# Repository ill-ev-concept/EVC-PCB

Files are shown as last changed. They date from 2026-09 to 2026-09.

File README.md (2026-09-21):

# EVC-PCB

*By: Himesh Nasaka*

Welcome to EV Concept's PCB Repo!

This is where all of our projects are stored. 

* Boards: Contains design files of all current boards being worked on
* Libs: Contains a wide selection of schematics, footprints, and models of components that are being used

# Getting Started

Start by having Git and KiCAD 10 downloaded. If you are using a older version of KiCAD, we recommend updating to the newest version. We also recommend installing Github Desktop in order to make the usage a bit cleaner.

Clone this repo. This can be either done through terminal or Github Desktop. Click the green dropdown labeled "<> Code" and select your preference of how to clone the repo. If using terminal, run the command below

```git clone [INSERT]```

If using Desktop, you can click the dropdown menu next to current repository, then "add", and finally "clone" where we can input the repo's url. 

# Setting Paths

After cloning, open KiCAD and find the "Preferences" dropdown and select "Configure Paths".
We are going to be adding three new paths. Create three new variables, ```EVC_SYMBOL_DIR```, ```EVC_FOOTPRINT_DIR```, and ```EVC_3DMODEL_DIR```. Link these to the location of the ```symbols```, ```footprints```, and ```3d_models``` folders contained with ```libs``` folder.

<img src="./images/Configure_Paths.png" width="700" alt="Example of Correct Paths">

When designing, we will need KiCAD to know to look at a given library. We can do this by going to "Preferences" and finding either "Manage Symbol Libraries" or "Manage Footprint Libraries". Opening either brings up a window where we can select "Project Specific Libraries" where we can add paths. Click the folder icon and add the wanted library. If you set the path up correctly, the library path will contain  ```${EVC_SYMBOL_DIR}```, ```${EVC_FOOTPRINT_DIR}```, or ```${EVC_3DMODEL_DIR}```. 

<img src="./images/Correct_Lib_Path.png" width="700" alt="Example of Library Paths">

# Contributing 

In order to begin designing, create a branch for your given board. This can be done through either the "current branch" dropdown in Desktop or using the command ```git checkout -b [branch name]```. You can swap branches using the same dropdown or either ```git checkout [branch name]```. 

<img src="./images/Branch.png" width="300" alt="Desktop Branch Dropdown">

This will be the branch where you will be doing your design work. Create a new KiCAD project and save the location into the boards folder of this repo. Everything onward will be traditional git. Use ```git add``` or check off the needed boxes on Desktop to add files for commit. ```git commit -m "[MESSAGE HERE]"``` will commit your changes. Make sure to write a meaningful commit message in order for good documentation. An example is shown below.

```git commit -m "Finished designing LDO and CANBus connectors, need to add MCU pinout and decoupling caps"```

<img src="./images/Commit_Msg.png" width="300" alt="Ex. of Good Commit Msg">

Input both your contributions and the next required steps in order to give reminders to both yourself and your teammates. 

Once a board is finished or you want it reviewed, it must be submitted via a pull request. This can be done using ```git push -u origin [branch name]``` or by clicking the branch dropdown in Desktop and selecting the "create pull request" option.

<img src="./images/Create_PR.png" width="300" alt="Create PR">

This will open up a Github tab on your browser where you can edit your pull request. Give it a good title and description so the design choices are clear and understandable. A title will also help the leads parse what you guys want done. 

<img src="./images/Comp_And_PR.png" width="500" alt="PR From Git Command">

You'll see the image above if you use a command line prompt and go to the repo.

<img src="./images/PR_In_Git.png" width="400" alt="Creating a Pull Request">

After the PR is submitted, we will decide on whether the board can be pushed to main or not. If it is not pushed, we will submit comments on what needs to be reviewed and edited. You can view open PRs and their comments in Github.

Apart from designing in KiCAD, it is important to be updating the libs folder when any new schematic, footprint, or model is added. First make sure the IC you want to add isn't currently within our library. Add the path to the specific library which is detailed more above. If the IC is not located in it's library, open Symbol/Footprint editor and select the library you want to add to. I recommended clicking the "View" dropdown, selecting the "Panels" option and adding the "Library Tree" option in order to easily see the connected libraries. 

<img src="./images/Library_Tree.png" width="300" alt="Library Tree">

From this, import the downloaded model and save the file. From there, push the updated library files and create a pull request. The leads will then check your work and merge it into main so everyone can use the IC.

When making pull requests for ICs, make sure to push them individually rather than with changes to other files. This will make it more clear for reviewers to understand that library files are being edited in addition to making sure that the change will be pushed to main. If you push with changes to your board and the pull request is not granted, people will not have access to the IC you have imported. 

Because the libs folder will be constantly updated, its also important to keep your branch up to date with new changes. We can layer on changes from main into our branch using a few different methods but the main one we will be using is merge. Run the command ```git fetch origin``` and then ```git merge origin``` in order to update changes. In Desktop, you can select "Update from main" from the "Branch" dropdown. 

<img src="./images/Update_From_Main.png" width="300" alt="Update from Main">

This should not change any local files that is stored and will update the libs folder to have the newest selection of ICs. I recommend doing this every time you work on your boards. It will also make sure a merge conflict won't be created, in which the same file from two different pull requests is edited, causing a lot of hassle for the writers of this repo. 

A general outline of what the workflow may look like is shown below:

```git checkout [branch name]``` -> Run this to swap to the branch you want to work on

```git fetch origin``` -> Run this to pull updates from main. Important for having updated libs

```git merge origin/main``` -> Merges the changes from the above command

```git add [file name]``` -> Add files for commit. When updating library files, make sure to add them in individual PRs

```git commit -m "[message here]"``` -> Commits your changes to be pushed into your branch

```git push -u origin [branch name]``` -> Run this command the first time you make the branch. It will link your branch to Github. 

```git push``` -> Pushes your changes. After, you can go to Github and create a pull request for the changes to be pushed into main. **Don't create a PR for every change you do.** Only create pull requests **IF** you are editing the libs folder **OR** you are submitting for board revision **OR** it is the final revision of the board.

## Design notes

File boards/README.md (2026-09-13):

# Boards!

This is the location where you will be pushing your KiCAD files to. 
Each file should be it's own project. You should only be pushing 5 different files
- kicad_pro
- kicad_sch
- kicad_pcb
- fp-lib-table
- sym-lib-table

*Nothing else should be pushed*

I'll be adding more details later on

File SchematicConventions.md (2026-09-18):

# **Schematic Conventions**

*By: Ethan Rybka*

Please make sure to follow these as close as possible, this will make schematic review much easier for leadership, and help project progress move forwards.

<br/>

# **Introduction**
When doing schematic layout, **consistency** is key to having a readable schematic. This means that you stick to a formatting convention for the whole schematic.

# **Labels**

When using labels use **regular** or **hierarchical** labels. Only use global labels when neccesary. 

### **Naming labels**

When naming labels, do **not** use spaces, use "_" or no space instead. Generally it is best to use all capital letters when naming.

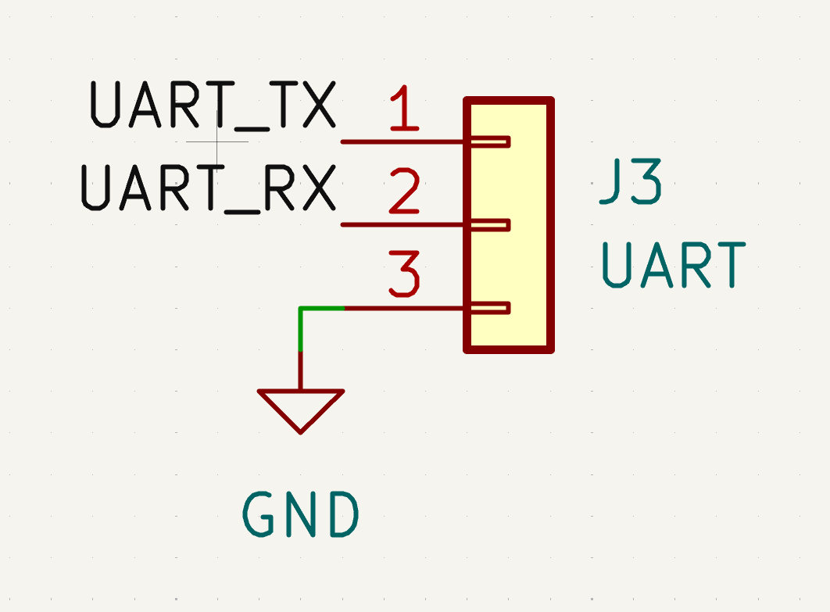
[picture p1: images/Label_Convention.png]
Label Conventions


### **Power Labels**

For power labels, GND must always face downwards, and power always upwards. Make sure you are using the built in symbols for these.

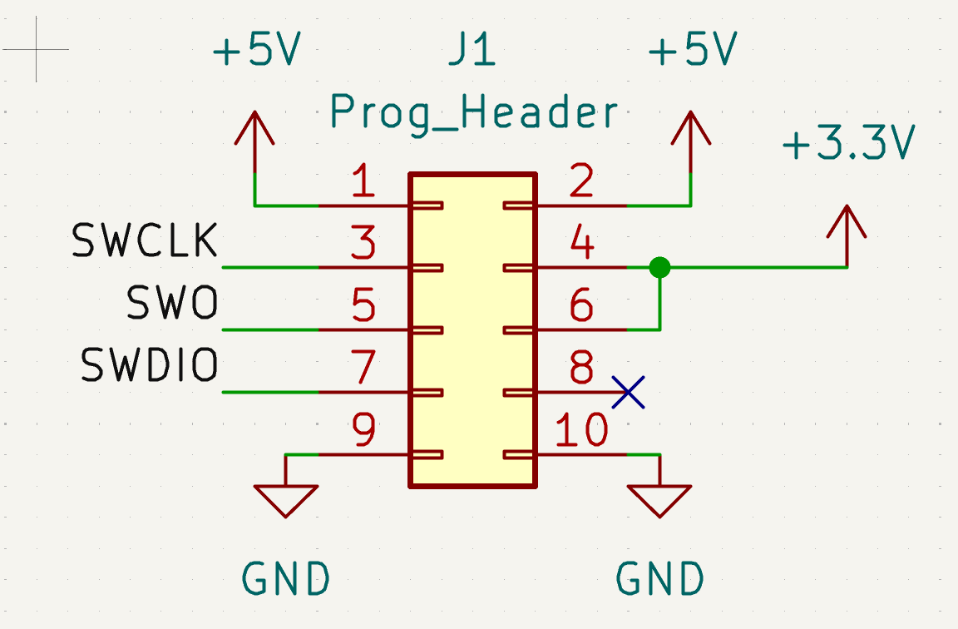
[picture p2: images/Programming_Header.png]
Power Label Conventions


# **Structure**

### **Partitions**

Whenever you can, try to group together sets of components together that have similar functionality. For example a buck converter circuit can be inside of one box.
Make sure to label each boxes function. Make sure the box has:

- 8 mil (0.25mm) line width
- Dashed lines
- Use at least 1.5mm (55 mil) text size

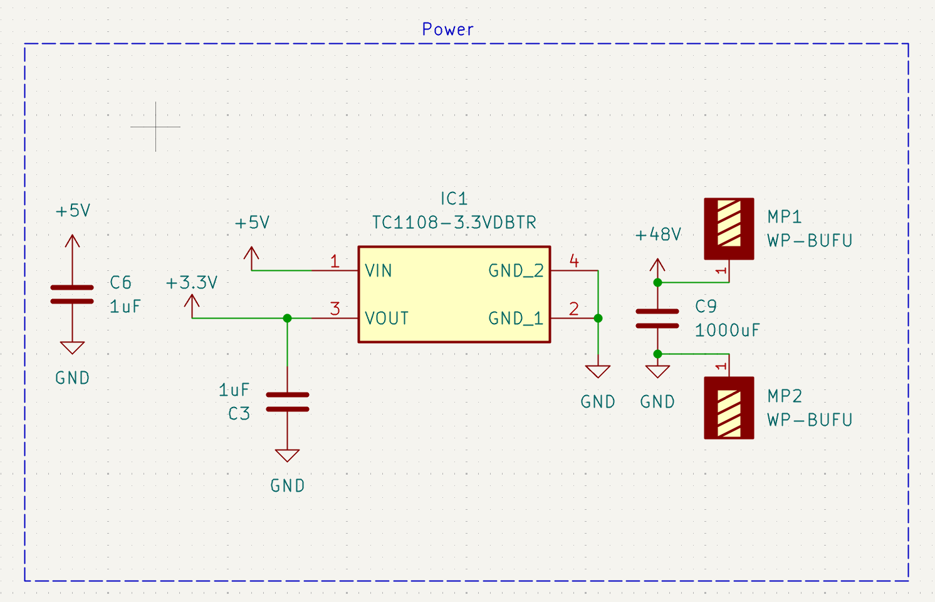
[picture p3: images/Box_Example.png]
Box/Partition Conventions


## **Sizes**

### **Page Size**

Page size can be any size, although larger sizes will be harder to print, using hierarchical sheets can help to 

### **Text**

Make sure any text follows the above 1.5 mm min text size for readability.

### **Grid** 

Keep the grid size the default size (1.27mm/50mil) if more accurate placement is needed, use half of the size (0.635mm/25mil).

### **Reference Designators & Component Values**

Make sure that components do not have overlapping designators, or component values, this helps with not only readability for you but also for whoever is reviewing your board.

## **EVC Specific Connections**

We have some specific standard layouts for connectors such as the programming headers and CANbus connections, as shown below

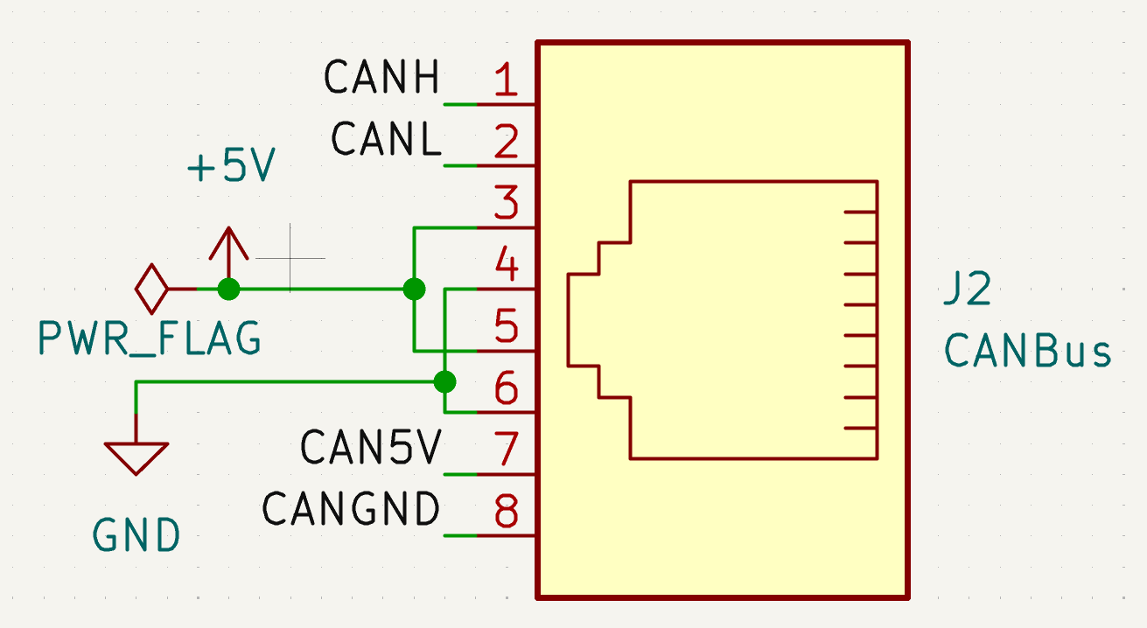
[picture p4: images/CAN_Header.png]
CAN Header
Programming Header  

# **Final Notes**

Just another reminder to be **CONSISTENT** across the entire board. This will make your life easier later on when something breaks and you have to figure why. Something will most likely go wrong the first time, nobody is perfect.

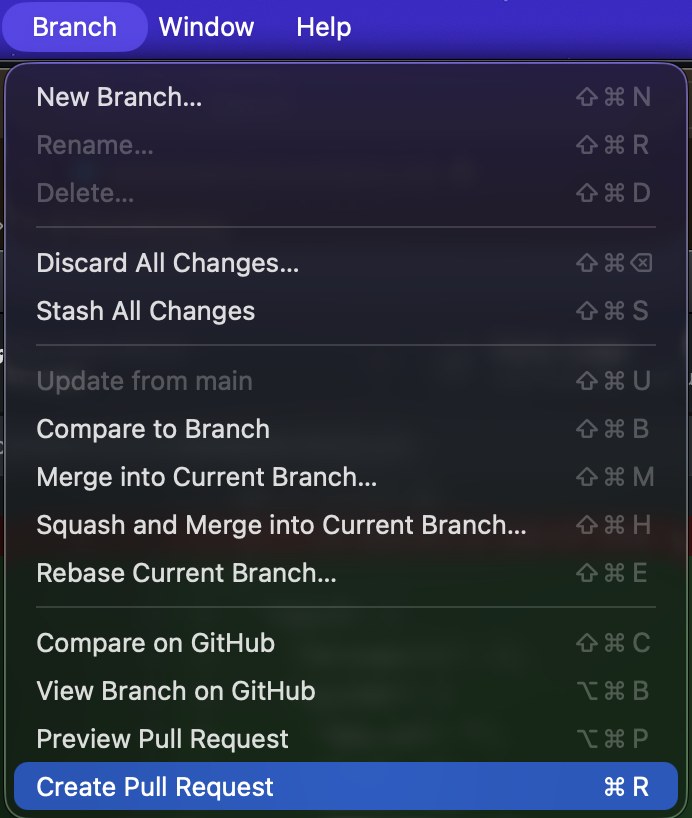
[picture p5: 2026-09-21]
images/Create_PR.png

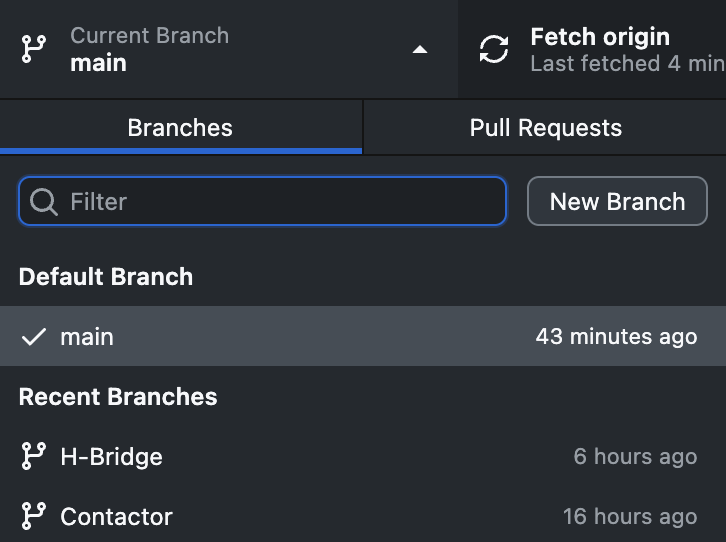
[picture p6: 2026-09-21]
images/Branch.png

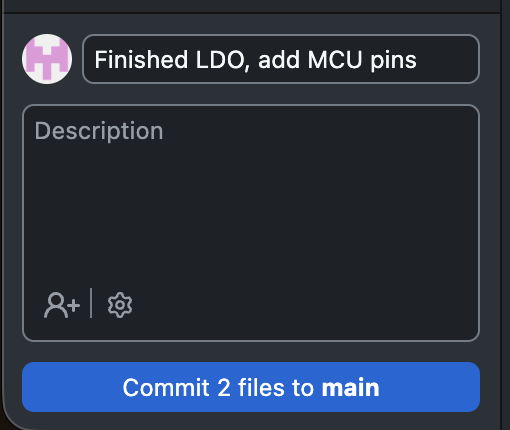
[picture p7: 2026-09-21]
images/Commit_Msg.png

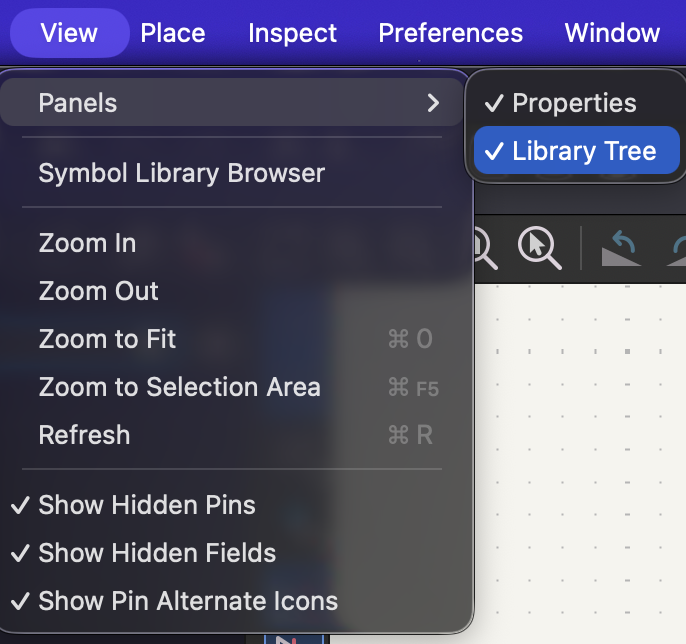
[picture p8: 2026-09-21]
images/Library_Tree.png

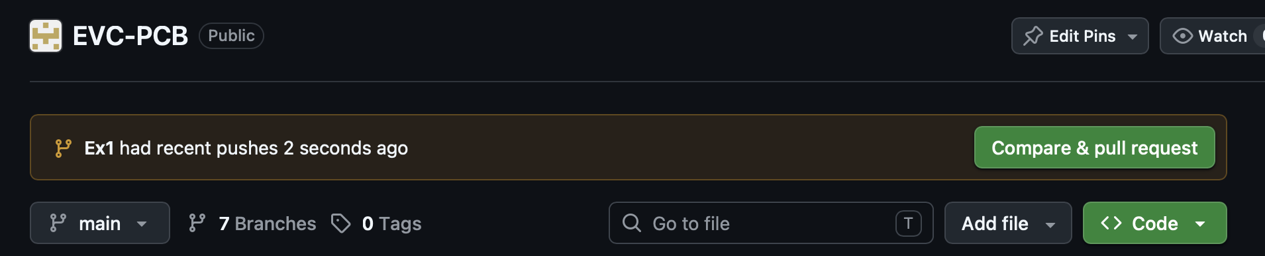
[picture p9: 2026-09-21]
images/Comp_And_PR.png

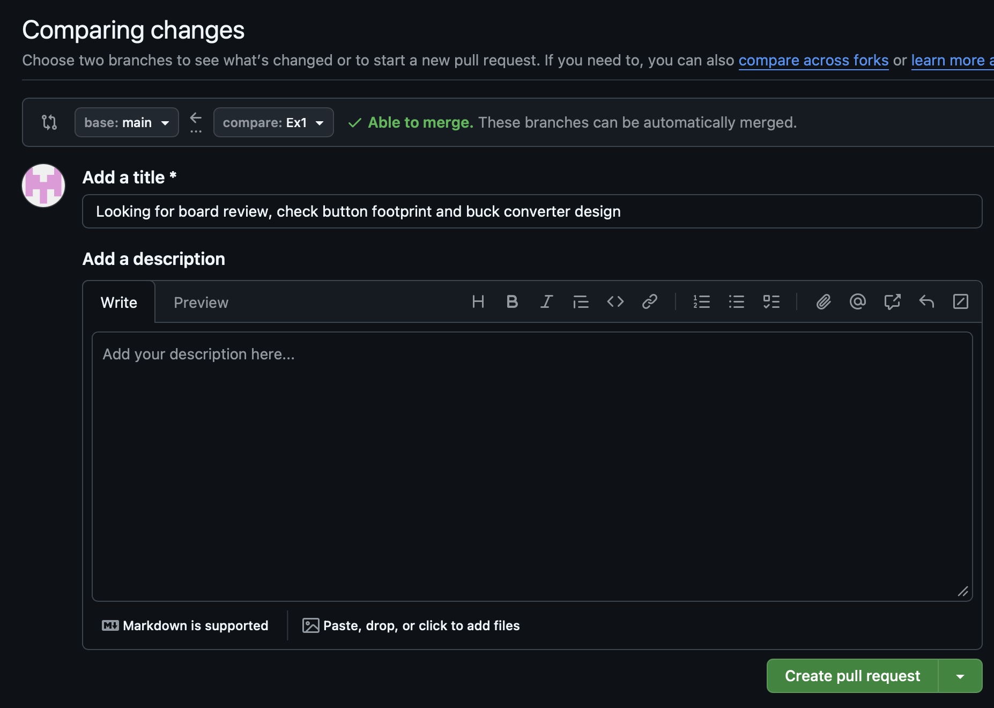
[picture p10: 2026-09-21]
images/PR_In_Git.png

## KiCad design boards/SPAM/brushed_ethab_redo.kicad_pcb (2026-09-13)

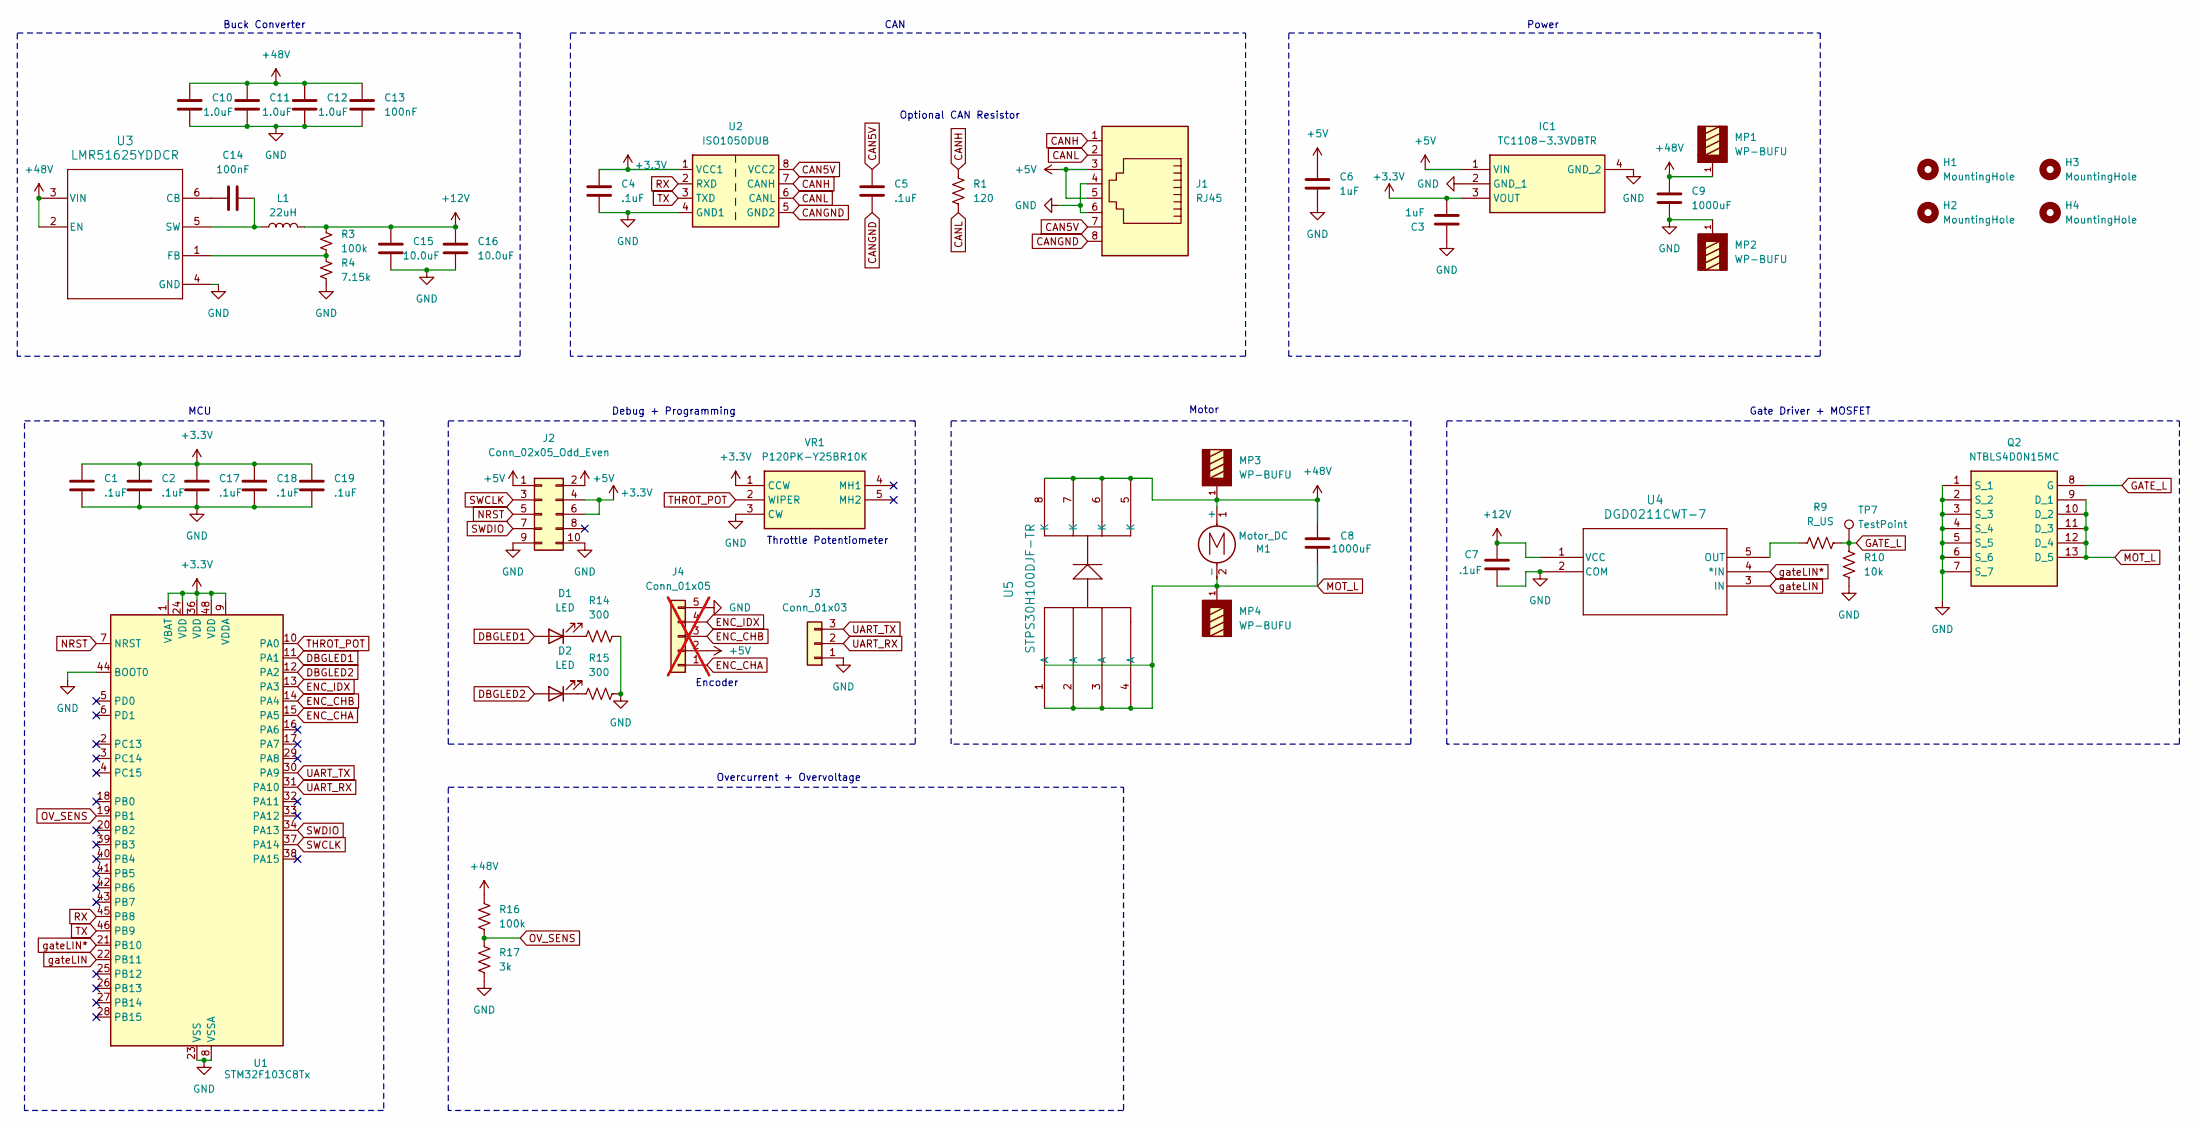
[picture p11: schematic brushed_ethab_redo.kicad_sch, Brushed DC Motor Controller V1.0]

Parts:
C1, C2, C4, C5, C7, C17, C18, C19: .1uF; C_0805_2012Metric_Pad1.18x1.45mm_HandSolder
C3, C6: 1uF; C_0805_2012Metric_Pad1.18x1.45mm_HandSolder
C8, C9: 1000uF; CP_Radial_D18.0mm_P7.50mm
C10, C11, C12: 1.0uF; C_1206_3216Metric
C13: 100nF; C_0603_1608Metric_Pad1.08x0.95mm_HandSolder
C14: 100nF; C_0402_1005Metric_Pad0.74x0.62mm_HandSolder
C15, C16: 10.0uF; C_1210_3225Metric
D1, D2: LED; LED_0805_2012Metric_Pad1.15x1.40mm_HandSolder
H1, H2, H3, H4: MountingHole; MountingHole_4.3mm_M4
IC1: TC1108-3.3VDBTR; SOT230P700X180-4N; Manufacturer_Part_Number TC1108-3.3VDBTR; Mouser Part Number 579-TC1108-3.3VDBTR
J1: RJ45; RJ45_Amphenol_54602-x08_Horizontal
J2: Conn_02x05_Odd_Even; PinSocket_2x05_P2.54mm_Vertical
J3: Conn_01x03; PinSocket_1x03_P2.54mm_Vertical
J4: Conn_01x05; PinSocket_1x05_P2.54mm_Vertical; not fitted
L1: 22uH; L_Bourns_SRR1208_12.7x12.7mm
M1: Motor_DC
MP1, MP2, MP3, MP4: WP-BUFU; WP-BUFU_7461097; DigiKey_Part_Number 732-3217-ND
Q2: NTBLS4D0N15MC; Manufacturer_Part_Number NTBLS4D0N15MC; Mouser Part Number 863-NTBLS4D0N15MC
R1: 120; R_0805_2012Metric_Pad1.20x1.40mm_HandSolder
R3: 100k; R_0402_1005Metric_Pad0.72x0.64mm_HandSolder
R4: 7.15k; R_0603_1608Metric_Pad0.98x0.95mm_HandSolder
R9: R_US; R_0805_2012Metric_Pad1.20x1.40mm_HandSolder
R10: 10k; R_0805_2012Metric_Pad1.20x1.40mm_HandSolder
R14, R15: 300; R_0805_2012Metric_Pad1.20x1.40mm_HandSolder
R16: 100k; R_0805_2012Metric_Pad1.20x1.40mm_HandSolder
R17: 3k; R_0805_2012Metric_Pad1.20x1.40mm_HandSolder
TP7: TestPoint; TestPoint_Pad_D1.0mm
U1: STM32F103C8Tx; LQFP-48_7x7mm_P0.5mm
U2: ISO1050DUB; SOP-8_6.62x9.15mm_P2.54mm
U3: LMR51625YDDCR; DDC0006A-MFG
U4: DGD0211CWT-7; TSOT25-TH_DIO
U5: STPS30H100DJF-TR; MOSFET_100DJF-TR_STM
VR1: P120PK-Y25BR10K; P120PKY25BR10K; Manufacturer_Part_Number P120PK-Y25BR10K; Mouser Part Number 858-P120PKY25BR10K

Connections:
+3.3V: C1.1, C2.1, C3.2, C4.1, C17.1, C18.1, C19.1, IC1.3 (VOUT), J2.4, J2.6, U1.1 (VBAT), U1.9 (VDDA), U1.24 (VDD), U1.36 (VDD), U1.48 (VDD), U2.1 (VCC1), VR1.1 (CCW)
+5V: C6.1, IC1.1 (VIN), J1.3, J1.5, J2.1, J2.2, J4.2
+12V: C7.1, C15.1, C16.1, L1.2, R3.1, U4.1 (VCC)
+48V: C8.1, C9.1, C10.1, C11.1, C12.1, C13.1, M1.1 (+), MP1.1, MP1.2, MP1.3, MP1.4, MP1.5, MP1.6, MP1.7, MP1.8, MP1.9, MP1.10, MP1.11, MP1.12, MP1.13, MP1.14, MP1.15, MP1.16, MP3.1, MP3.2, MP3.3, MP3.4, MP3.5, MP3.6, MP3.7, MP3.8, MP3.9, MP3.10, MP3.11, MP3.12, MP3.13, MP3.14, MP3.15, MP3.16, R16.2, U3.2 (EN), U3.3 (VIN), U5.5 (K), U5.6 (K), U5.7 (K), U5.8 (K)
CAN5V: C5.1, J1.7, U2.8 (VCC2)
CANGND: C5.2, J1.8, U2.5 (GND2)
CANH: J1.1, R1.1, U2.7 (CANH)
CANL: J1.2, R1.2, U2.6 (CANL)
DBGLED1: D1.2 (A), U1.11 (PA1)
DBGLED2: D2.2 (A), U1.12 (PA2)
ENC_CHA: J4.1, U1.15 (PA5)
ENC_CHB: J4.3, U1.14 (PA4)
ENC_IDX: J4.4, U1.13 (PA3)
GATE_L: Q2.8 (G), R9.2, R10.2, TP7.1 (1_1)
GND: C1.2, C2.2, C3.1, C4.2, C6.2, C7.2, C9.2, C10.2, C11.2, C12.2, C13.2, C15.2, C16.2, C17.2, C18.2, C19.2, IC1.2 (GND_1), IC1.4 (GND_2), J1.4, J1.6, J2.9, J2.10, J3.1, J4.5, MP2.1, MP2.2, MP2.3, MP2.4, MP2.5, MP2.6, MP2.7, MP2.8, MP2.9, MP2.10, MP2.11, MP2.12, MP2.13, MP2.14, MP2.15, MP2.16, Q2.1 (S_1), Q2.2 (S_2), Q2.3 (S_3), Q2.4 (S_4), Q2.5 (S_5), Q2.6 (S_6), Q2.7 (S_7), R4.2, R10.1, R14.2, R15.2, R17.1, U1.8 (VSSA), U1.23 (VSS), U1.35 (VSS), U1.44 (BOOT0), U1.47 (VSS), U2.4 (GND1), U3.4 (GND), U4.2 (COM), VR1.3 (CW)
MOT_L: C8.2, M1.2 (-), MP4.1, MP4.2, MP4.3, MP4.4, MP4.5, MP4.6, MP4.7, MP4.8, MP4.9, MP4.10, MP4.11, MP4.12, MP4.13, MP4.14, MP4.15, MP4.16, Q2.9 (D_1), Q2.10 (D_2), Q2.11 (D_3), Q2.12 (D_4), Q2.13 (D_5), U5.1 (A), U5.2 (A), U5.3 (A), U5.4 (A)
NRST: J2.5, U1.7 (NRST)
unnamed: D1.1 (K), R14.1
unnamed: D2.1 (K), R15.1
unnamed: C14.1, U3.6 (CB)
unnamed: R3.2, R4.1, U3.1 (FB)
unnamed: C14.2, L1.1, U3.5 (SW)
unnamed: R9.1, U4.5 (OUT)
OV_SENS: R16.1, R17.2, U1.19 (PB1)
RX: U1.45 (PB8), U2.2 (RXD)
SWCLK: J2.3, U1.37 (PA14)
SWDIO: J2.7, U1.34 (PA13)
THROT_POT: U1.10 (PA0), VR1.2 (WIPER)
TX: U1.46 (PB9), U2.3 (TXD)
UART_RX: J3.2, U1.31 (PA10)
UART_TX: J3.3, U1.30 (PA9)
gateLIN: U1.22 (PB11), U4.3 (IN)
gateLIN*: U1.21 (PB10), U4.4 (*IN)

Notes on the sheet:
Buck Converter
Power
Encoder
Optional CAN Resistor
Throttle Potentiometer
Motor
MCU
CAN
Gate Driver + MOSFET
Overcurrent + Overvoltage
Debug + Programming

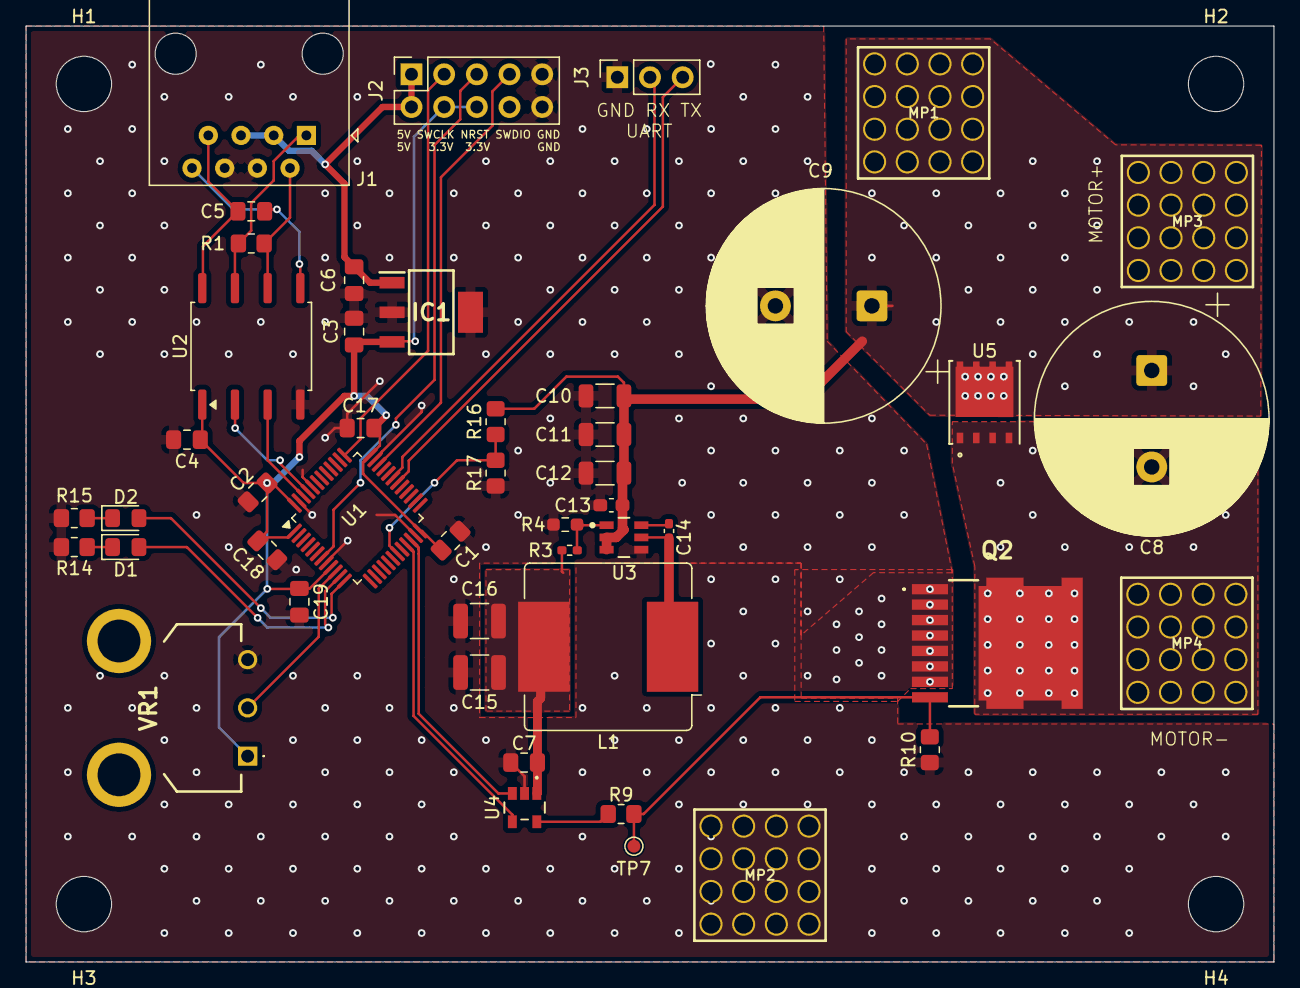
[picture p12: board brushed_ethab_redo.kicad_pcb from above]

Board: 2 copper layers, 97.0 x 72.8 mm, 51 parts (0 on the bottom side), 30 nets.

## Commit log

2026-09-13 added board and library files
2026-09-13 Adding boards folder, added README for boards
2026-09-13 added libraries, updated paths for Ethan's motor board
    [brushed_ethab_redo.kicad_pcb, brushed_ethab_redo.kicad_sch]
2026-09-15 Add PCB Files to H-Bridge, test branching
    [brushed_v2.kicad_pcb, brushed_v2.kicad_sch]
2026-09-15 Moved components to EVC lib
    [brushed_v2.kicad_sch]
2026-09-18 added footprint to test
2026-09-18 added images to schematic conventions
    [brushed_ethab_redo.kicad_sch]
2026-09-20 creating board files, will finish later
    [Contactor.kicad_pcb, Contactor.kicad_sch]
2026-09-21 removed extra footprint libs
2026-09-21 Add new sheet for HV, add components
    also figured out hierarchical labels
    [High_Voltage.kicad_sch, brushed_v2.kicad_sch]
2026-09-21 Added symbols + fixed sheet layout, low voltage nearly complete
    [High_Voltage.kicad_sch, brushed_v2.kicad_sch, h-bridge_top.kicad_sch]
2026-09-23 added fet sym, hv schematic changes
    [High_Voltage.kicad_sch]
2026-09-23 finished schematic (i think), added footprints
    [High_Voltage.kicad_sch, brushed_v2.kicad_sch, h-bridge_top.kicad_sch]
2026-09-23 added bulk caps to h bridge
    [High_Voltage.kicad_sch]
2026-09-25 create logo footprint
2026-09-27 finished schematic, added footprint assignments
    [High_Voltage.kicad_sch, brushed_v2.kicad_sch, h-bridge_top.kicad_sch]
2026-09-28 add pcb
    [brushed_v2.kicad_pcb]
2026-09-28 Made Project File
    Github stopped hating and I was able to make the KiCad Project in the right branch, will make schematic :)
    [DashboardV2.0.kicad_pcb, DashboardV2.0.kicad_sch]
2026-09-28 Made a sheet (LCD) for schematic
    Testing out if we can make hierarchical subsheets.
    [DashboardV2.0.kicad_sch, LCD_sch.kicad_sch]
2026-09-28 Made MCU Subsheet
    Made a subsheet for MCU parts, will finish making other sheets
    [DashboardV2.0.kicad_sch, MCU.kicad_sch]
2026-09-28 Tried Subsheets Again
    tried to make subsheets again because it didn't push properly the first time, will make schematic if it works
2026-09-28 File in wrong spot
    realized it was in the wrong spot, moved it to the right folder, hopefully it works. will continue schematic if it works.
    [EVC Dashboard V2.kicad_pcb, EVC Dashboard V2.kicad_sch, MCU.kicad_sch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]
2026-09-28 Added overvoltage subsheet
    [EVC Dashboard V2.kicad_sch, overvoltage.kicad_sch]
2026-09-28 Remove extra files (created on accident)
    [DashboardV2.0.kicad_pcb, DashboardV2.0.kicad_sch, LCD_sch.kicad_sch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]
2026-09-28 Added LCD to LED & Displays symbol library
    NHD-C12864A1Z-FSW-FBW-HTT display
2026-09-29 started pcb layout, added small LEDs and SWO to schematic
    [brushed_v2.kicad_pcb, brushed_v2.kicad_sch, h-bridge_top.kicad_sch]
2026-09-29 Added 3.3V LDO
    Added the LDO we want to use for the dashboard
2026-10-02 Uploading LDO 3.3 (ADP3338AKCZ-3.3RL7) footprint for dashboard
2026-10-02 Added footprint and symbol for STLINK-V3MODS
2026-10-02 Added encoder for dashboard
    Adding symbol for encoder for dashboard
2026-10-02 Added the backlight driver
    Added the dashboard's backlight driver MAX1554
2026-10-02 CAN transceiver footprint
2026-10-02 Adding footprint and symbol for display's 40pos ribbon connector, also updated description for old display
2026-10-02 modified pwm signals to be on same timer
    [brushed_v2.kicad_pcb, brushed_v2.kicad_sch]
2026-10-03 Added Dashboard MCU Connections
    Started wiring MCU connections that are unrelated to display, after deciding on display, will finish wiring MCU
    [MCU.kicad_sch]
2026-10-03 Dashboard schematic changes
    [overvoltage.kicad_sch]
2026-10-04 Overvoltage Protection component & mosfet addition
    [overvoltage.kicad_sch]
2026-10-04 did some layout
    [High_Voltage.kicad_sch, brushed_v2.kicad_pcb]
2026-10-05 thought some more
    [brushed_v2.kicad_pcb]
2026-10-06 added negative voltage per h-bridge docs
    [High_Voltage.kicad_sch, brushed_v2.kicad_pcb]
2026-10-09 changed pins for encoder to match embedded
    [brushed_v2.kicad_sch]
2026-10-11 fixed some schematic issues
2026-10-12 FET layout nearing completion
2026-10-13 moved components to better current sense
2026-10-13 Began proper FET layout/routing
    need to fully define the copper layers, currently not well defined, also need to figure out how to get 12v to the gate driver
2026-10-18 updated schematic
2026-10-18 added regulator footprint
2026-10-19 made interactive BOM plus added via stich and labels
    Jeremy
2026-10-19 added another cursed silkscreen
2026-10-25 Update Fasteners & Fixings.kicad_sym
2026-10-31 Update Footprints for ISO1042QDWVQ1 and WP_BUTR
2026-11-03 adding BOM plus missing decoupling cap
2026-11-03 changed footprint for component availability/update BOM
2026-11-09 added new CAN connector, updated readme
